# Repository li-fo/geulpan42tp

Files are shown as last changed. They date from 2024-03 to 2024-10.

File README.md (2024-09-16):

# GeulPan42TP Keyboard

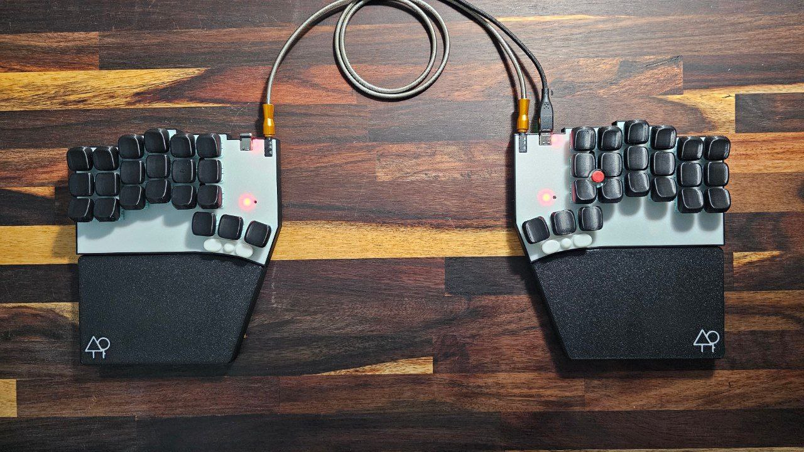
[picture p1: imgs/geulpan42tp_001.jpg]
GeulPan42TP


"GeulPan(글판)" means a keyboard.

GeulPan42TP is a split keyboard with 3x6 column staggered keys and 3 thumb keys.
and TrackPoint with 3 keys.

- MCU : YD-RP2040
- Trackpoint Module : 2-piece Tracpoint for X240, X250, X260 X270
    - if using tp mouse btn, can't drag. so need to use QMK Mouse btn
    - Ref [How to integrate a trackpoint in a mechanical keyboard](https://github.com/alonswartz/trackpoint)
- diodeless
- Split and rgblight (YD-RP2040 internal WS2812)
- tenting and palm rest
- keycap : [KLP LAME MX](https://github.com/braindefender/KLP-Lame-Keycaps)

### Ref Links

- [How to integrate a trackpoint in a mechanical keyboard](https://github.com/alonswartz/trackpoint)
- [TrackPoint](https://github.com/joric/jorne/wiki/Trackpoint)
- [TrackPoint Hardware from deskthority](https://deskthority.net/wiki/TrackPoint_Hardware)
- [TrackPoint System Version 4.0 Engineering Specification](https://blogs.epfl.ch/icenet/documents/Ykt3Eext.pdf)

## Caution

Although I made this and am currently using it, there appears to be a bug affecting the trackpoint operation. Therefore, unless using a trackpoint is essential for you, it may be better to consider a different split keyboard.

### Other Split keyboard with integrated trackpoint

- [TPS42](https://github.com/crehmann/TPS42)
- [Santoku Keyboard Kit](https://gestaltinput.com/products/santoku-keyboard-kit-black)

## Images

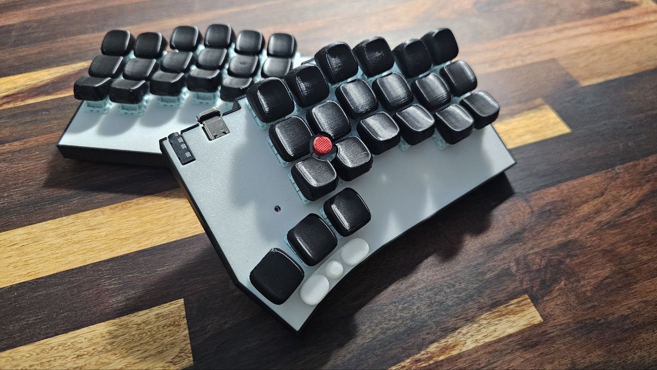
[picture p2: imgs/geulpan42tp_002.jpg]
GeulPan42TP


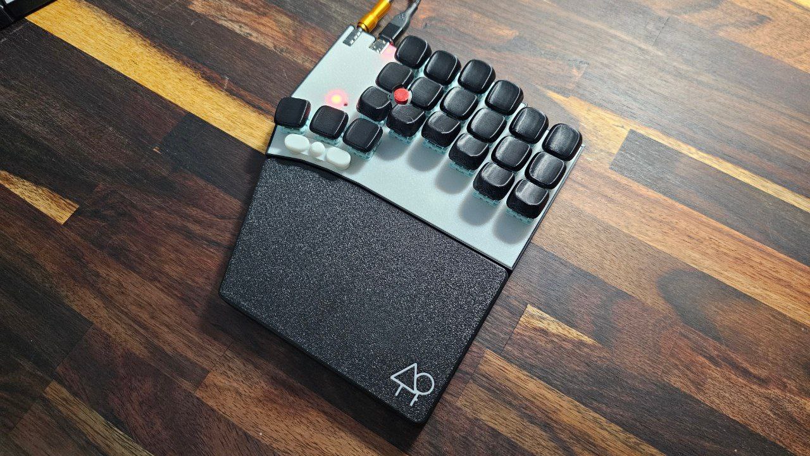
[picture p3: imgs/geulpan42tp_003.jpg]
GeulPan42TP


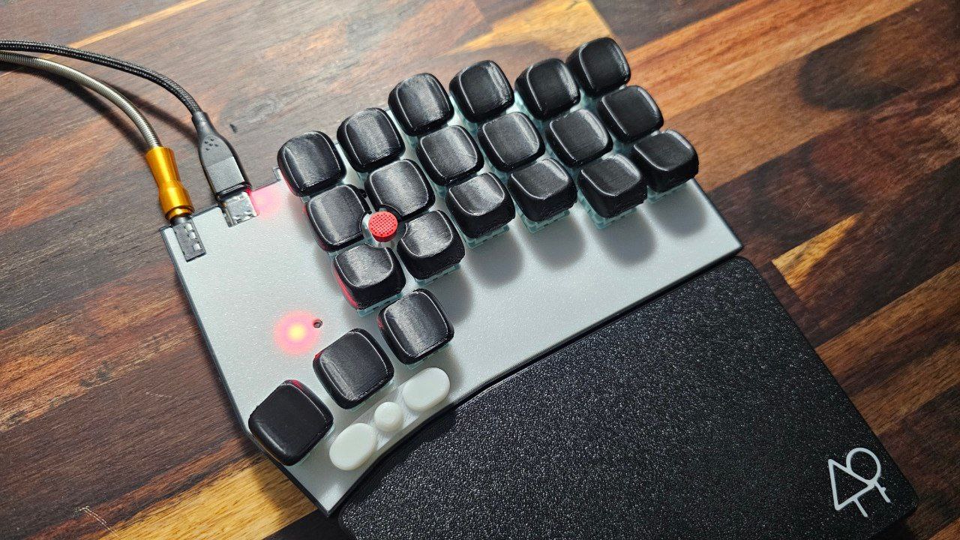
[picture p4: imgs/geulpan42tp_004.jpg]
GeulPan42TP


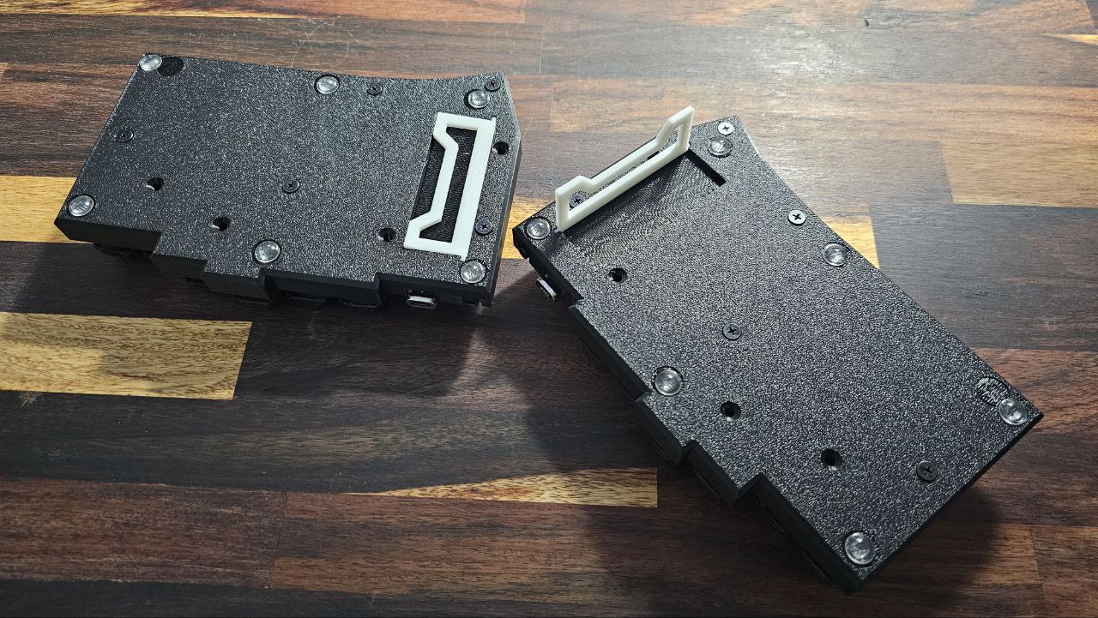
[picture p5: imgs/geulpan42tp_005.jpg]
GeulPan42TP


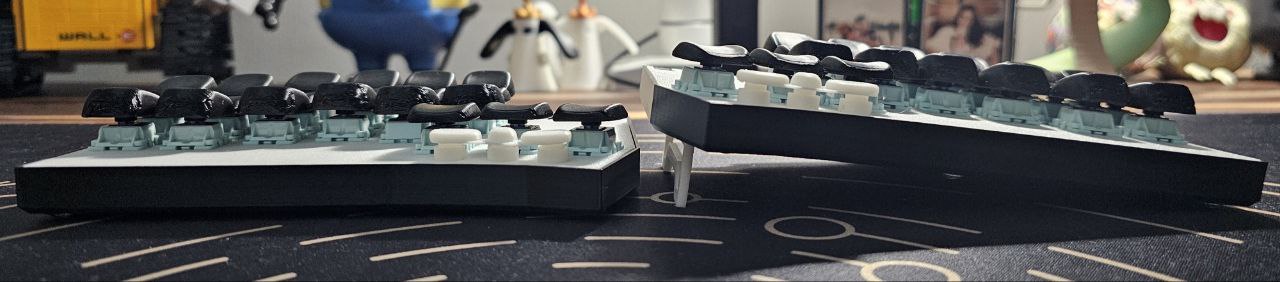
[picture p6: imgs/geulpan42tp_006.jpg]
GeulPan42TP


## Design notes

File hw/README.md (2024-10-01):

## BOM

### Base

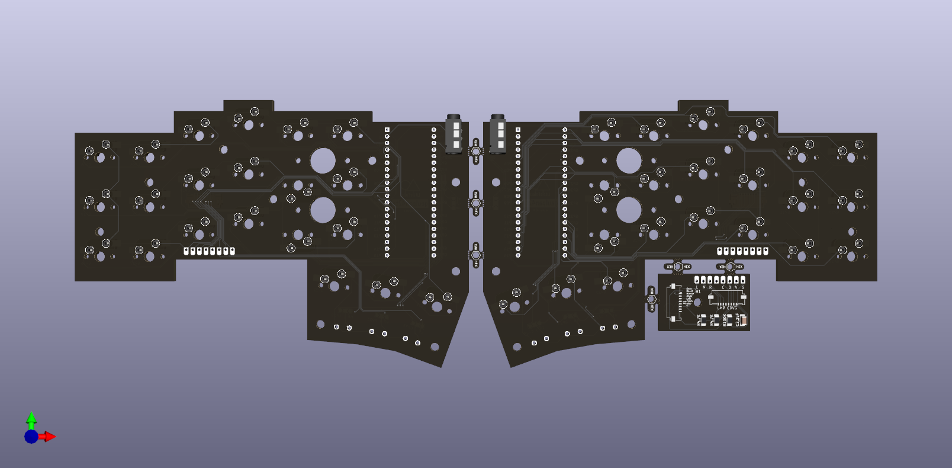
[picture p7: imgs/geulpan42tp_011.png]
GeulPan42TP


| Part  | Qty | Memo |
| --- | --- | --- |
| YD-RP2040  | 2  | -  |
| PJ321A  | 2 | -  |

### TrackPoint

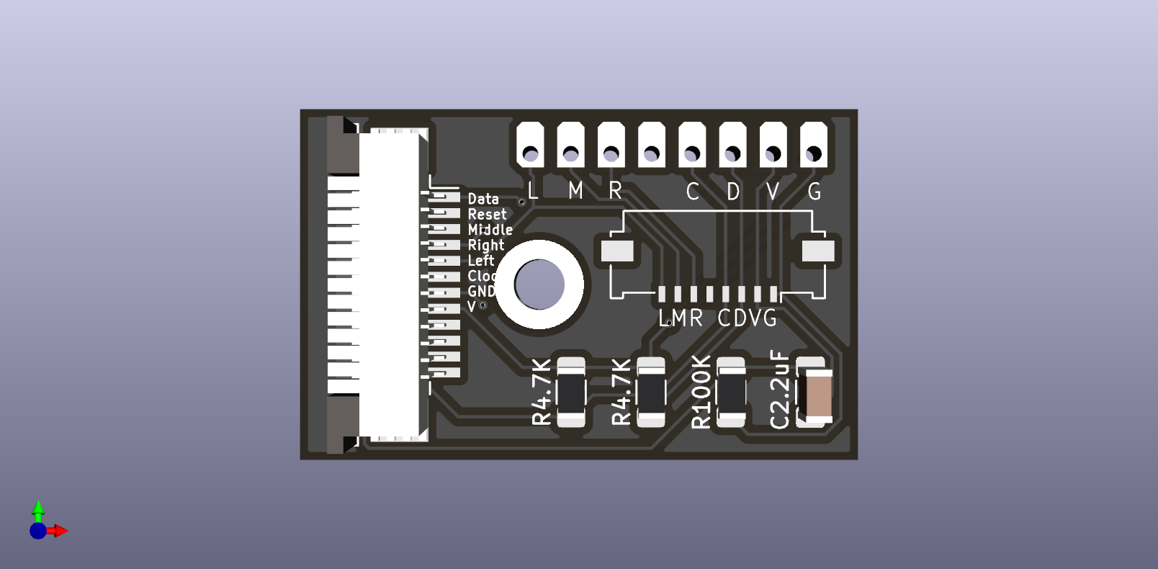
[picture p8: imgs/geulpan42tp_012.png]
GeulPan42TP


TrackPoint Module : 2-piece Tracpoint for X240, X250, X260 X270

| Part  | Qty | Size or Spec |
| --- | --- | --- |
| 4.7k  | 2  | 1206  |
| 100k  | 1 | 1206  |
| 2.2uF  | 1  | 1206  |
| FFC 12 Pin Connector*  | 1  | under contact  <br> if not a Molex 200528-0120, need to cut both ends of the cable |
| FFC 8 Pin Connector  | 2  | under contact |
| FFC 8 Pin Cable*  | 1  | reverse direction(right side, default) <br> forward direction (left side)  |
| 6x6x3.5  | 6  | -  |
| M2 x 4mm Philips flathead bolt | 2  | -  |

If you're not using an FFC cable, you can also solder it as shown in the picture.

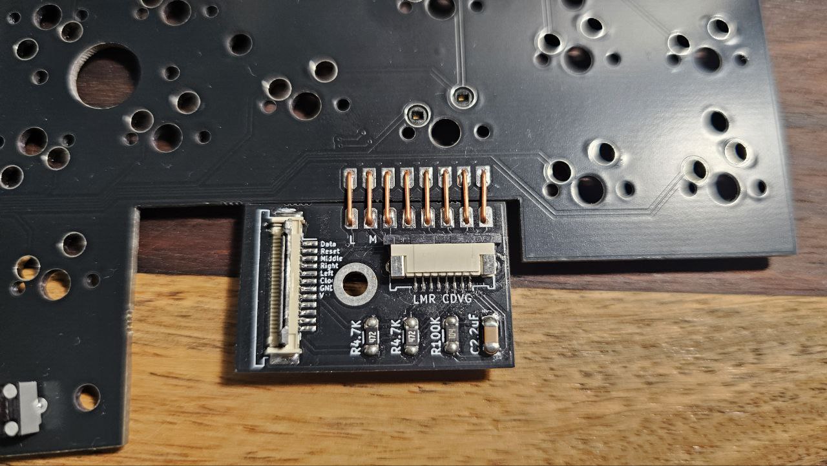
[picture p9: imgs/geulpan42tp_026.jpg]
GeulPan42TP


### Case & PalmRest

| Part  | Qty | Size |
| --- | --- | --- |
| Bolt  | 10  | M3 6mm  |
| Bumpon  | 12  | SJ5032 or 10mm  |
| Mganet | 6  | 6mm x 2mm  |

### Keycaps for Trackpoint

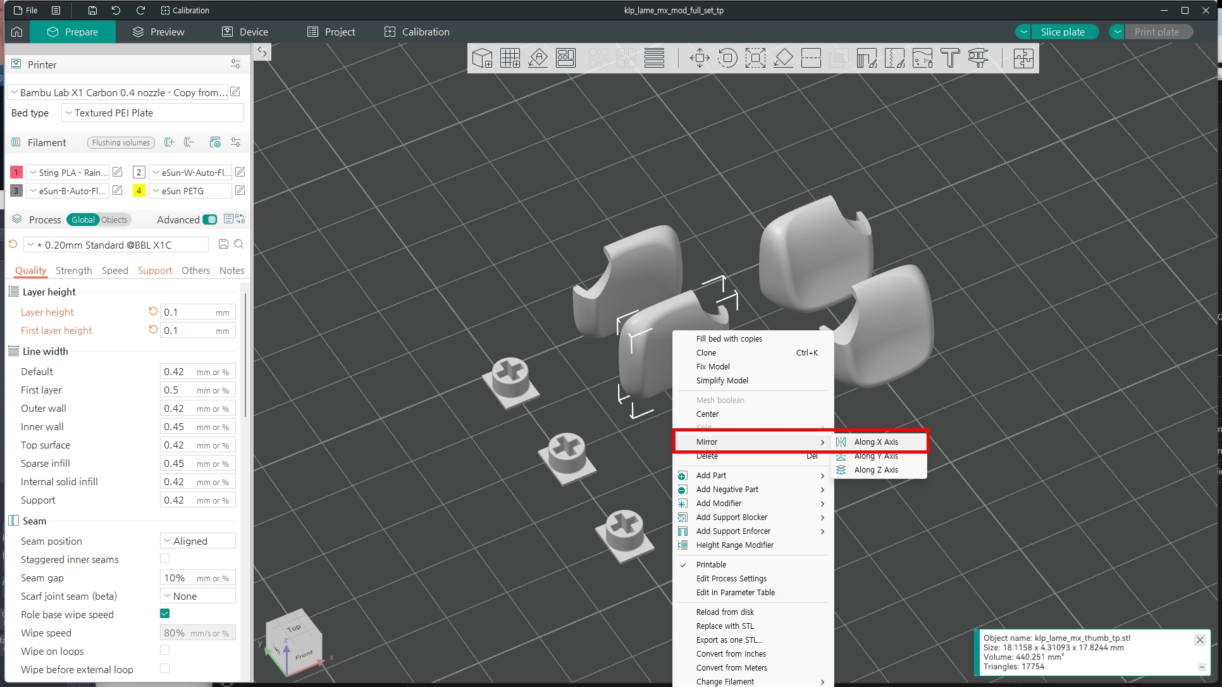
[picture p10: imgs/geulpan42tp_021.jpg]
GeulPan42TP


I have modified and created the [KLP Lame Sallde for MX](https://github.com/braindefender/KLP-Lame-Keycaps) keycap. The print settings are as follows:

| Option  | Value | Memo |
| --- | --- | --- |
| Layer Height  | 0.1 | - |
| Support  | Tree Support  | -  |

### Sodering Option

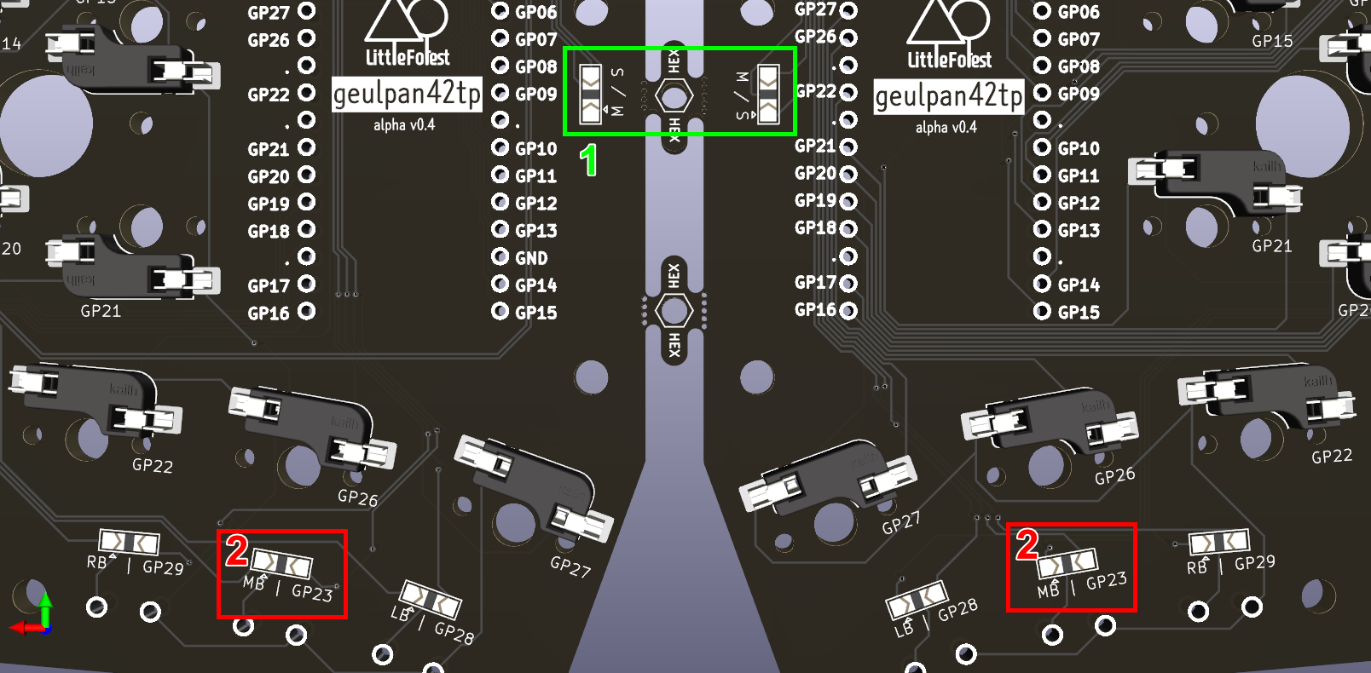
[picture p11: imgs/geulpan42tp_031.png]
GeulPan42TP


I'm primarily using the trackpoint attached on the right side by default, but I've made it possible to choose between master and slave for those who want to attach the trackpoint on the left side. However, I haven't tested it with the trackpoint mounted on the left side. 

1. Master or Slave
    -  I have set it up so that the side with the trackpoint installed is the master, and the side without it is the slave. Power is supplied from the master to the slave.
    - By default, the right side is the master and the left side is the slave
    - The default soldering position is marked as "▲"

2. Mouse Button 
    - The default soldering position is marked as "▲" and Using Trackpoint Mouse Button.
    - You can use either the trackpoint's mouse buttons or the QMK mouse buttons.If the trackpoint mouse operation is not smooth, you can switch to the QMK mouse buttons.
    - If using QMK mouse buttons, the left and right buttons can be used immediately by changing their soldering positions.
    - To use the middle mouse button as a QMK mouse button, you need to desolder the RGB section of the yd-rp2040 board.

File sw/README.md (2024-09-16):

# GeulPan42TP Keyboard

If you can't drag while using the trackpoint, please use "PS2_MOUSE_USE_REMOTE_MODE". 

However, for parts where the trackpoint is not connected, you should use "Stream Mode".

"PS/2 mouse" was not connected, using "remote mode" caused the controller to malfunction.

example : Master Side use "PS2_MOUSE_USE_REMOTE_MODE", Slave Side use "Stream Mode"

If the cursor malfunctions when using "remote mode", please reconnect the keyboard.

As a temporary solution to this problem, I have enabled the option to solder GP28 and GP29.
If you solder GP28 and GP29, you will be able to assign and use QMK mouse buttons.

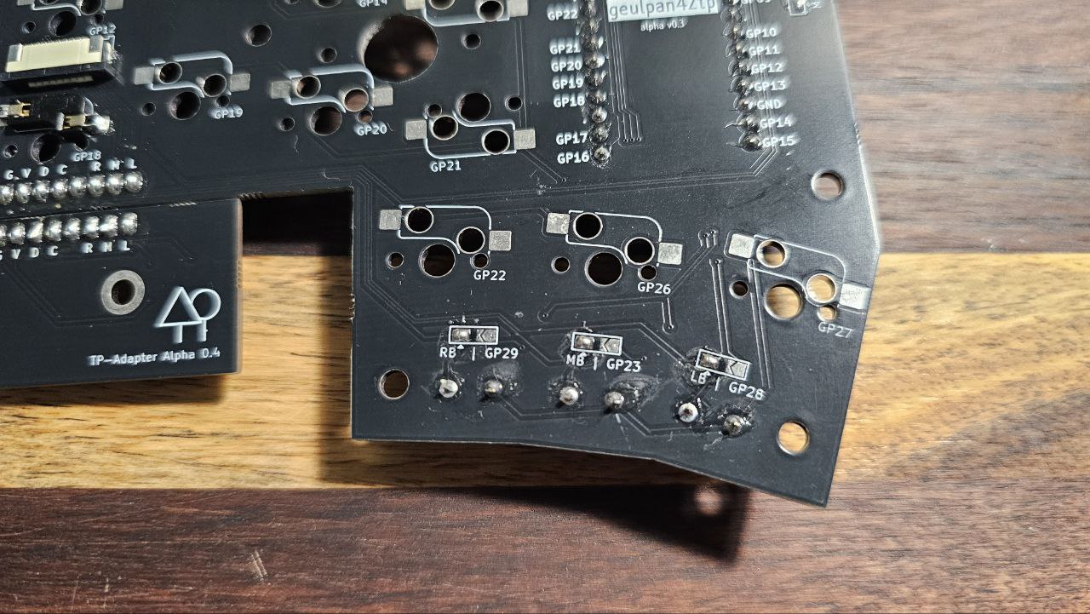
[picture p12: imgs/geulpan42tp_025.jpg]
GeulPan42TP


## TrackPoint movement activate mouse layer

When using the trackpoint, you can use the "Movement Hook" to automatically activate the mouse layer.
The default value is FALSE. This is because it was inconvenient when the trackpoint was often touched while typing.

To activate it, please change the "MOUSE_LAYER_AUTO_ENABLE" item in config.h from FALSE to TRUE.

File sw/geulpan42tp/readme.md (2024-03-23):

# GeulPan42TP Keyboard

"GeulPan(글판)" means a keyboard.

GeulPan42TP is a 42 keyboard with Trackpoint.

RP2040, split, diodeless, Trackpoint, rgblight(YD-RP2040 internal WS2812)

currently POC stage. 

- TrackPoint Module : 2-piece Trackpoint for X240, X250, X260 X270
    - if using tp mouse button, can't drag. so need to use QMK mouse button
    - Ref [How to integrate a trackpoint in a mechanical keyboard](https://github.com/alonswartz/trackpoint)

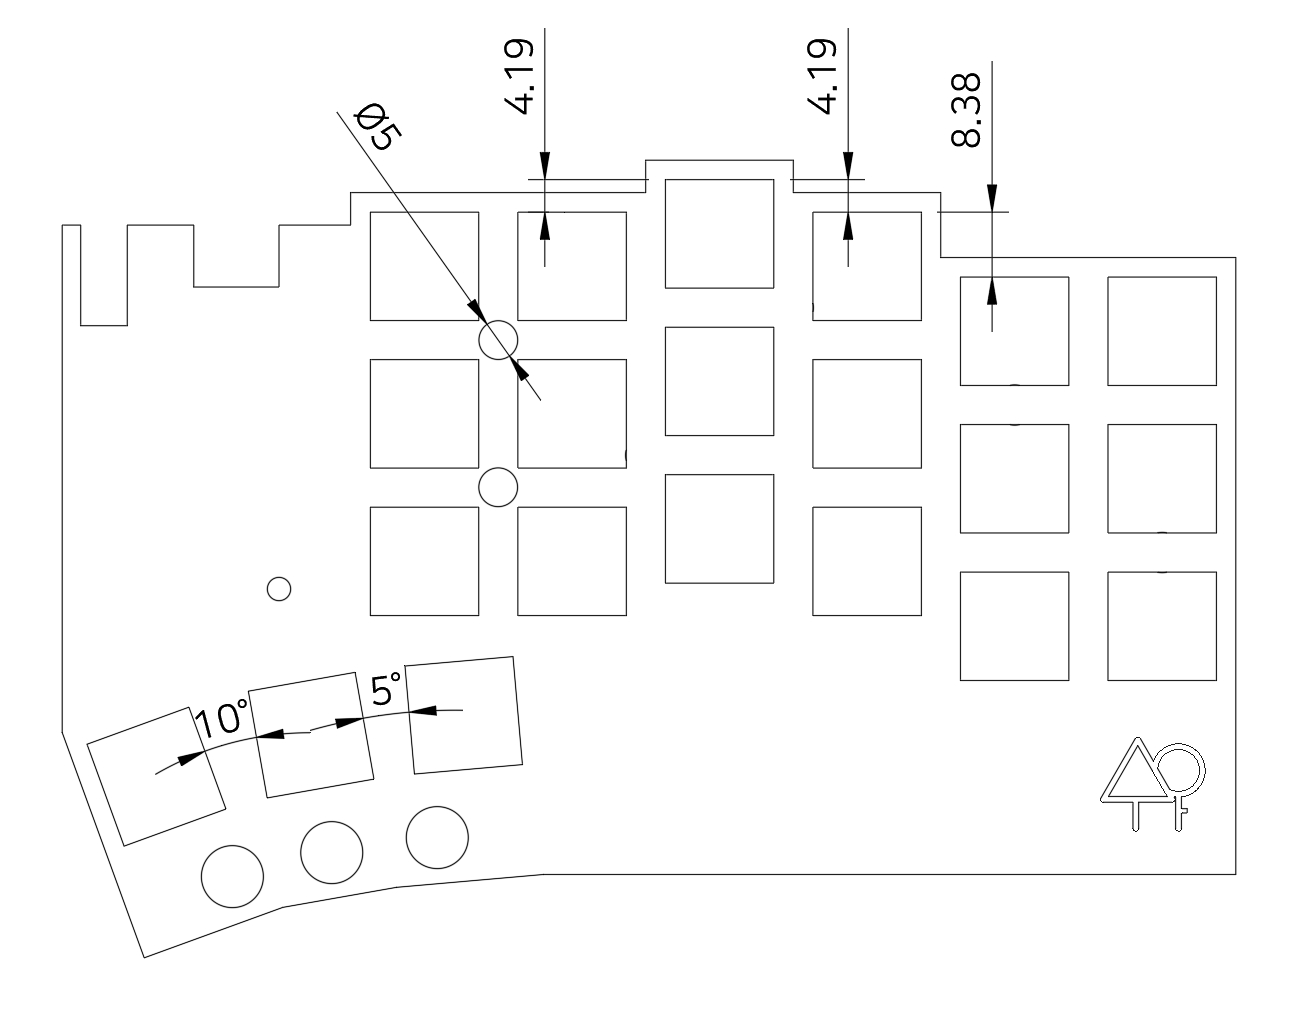
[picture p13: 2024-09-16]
imgs/geulpan42tp_007.jpg

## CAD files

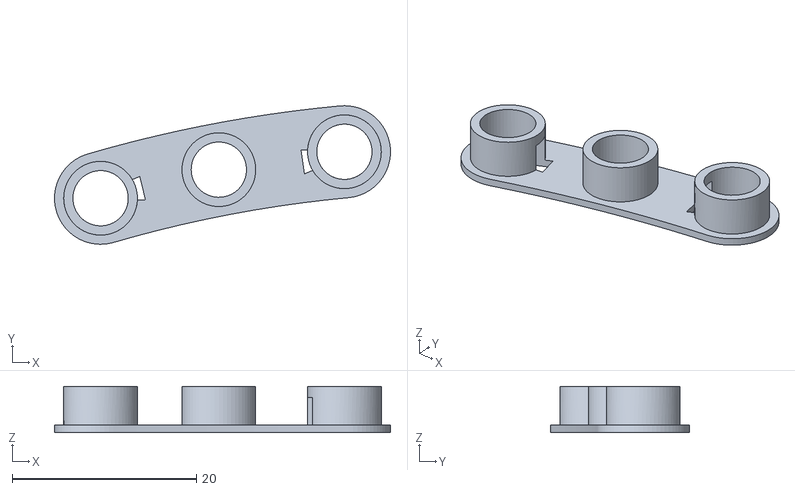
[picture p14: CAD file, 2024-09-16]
hw/stls/05-02 Mouse-BTN-Support.stl
36.5 x 15.0 x 5.00

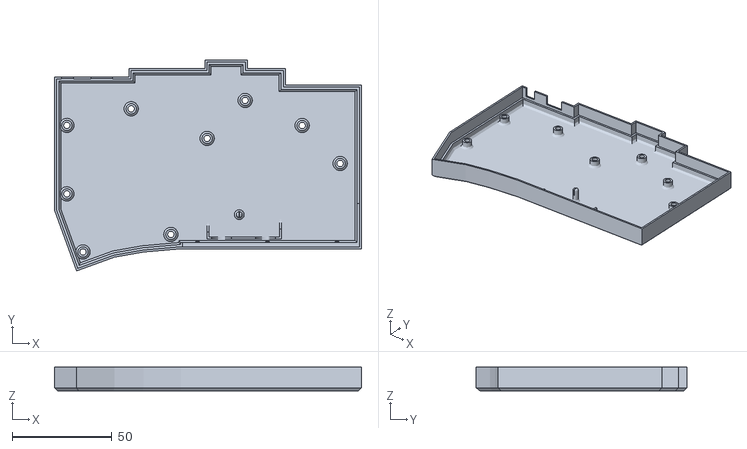
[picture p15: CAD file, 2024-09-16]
hw/stls/01 gp42tp-case-v0.1.stl
154.0 x 105.7 x 12.0

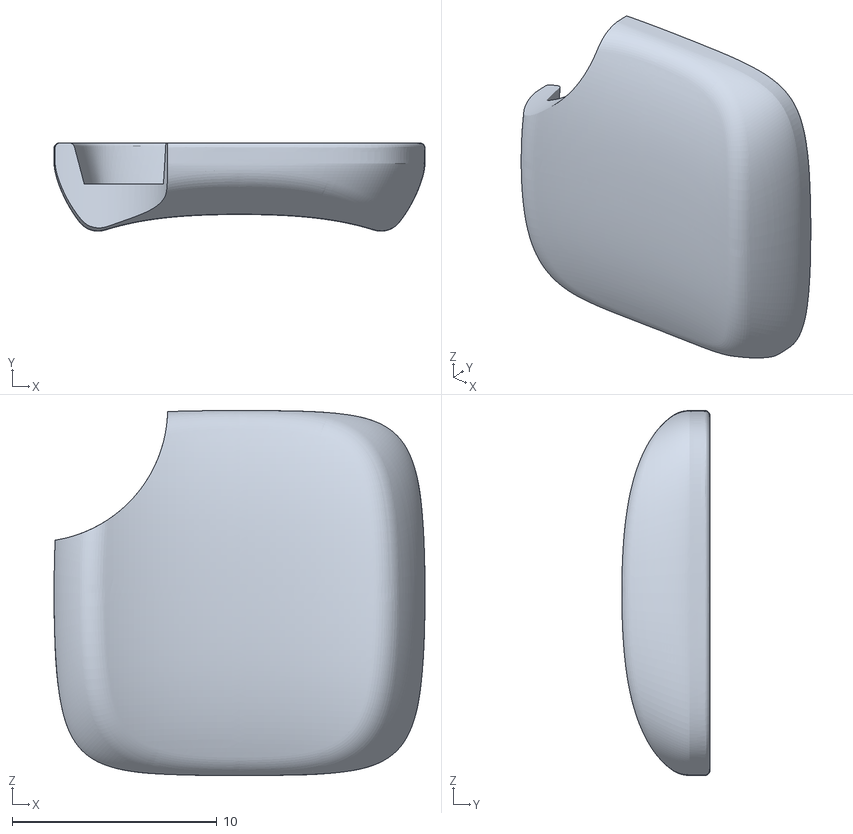
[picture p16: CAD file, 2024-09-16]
hw/stls/15 klp_lame_mx_thumb_tp.stl
18.1 x 4.31 x 17.8

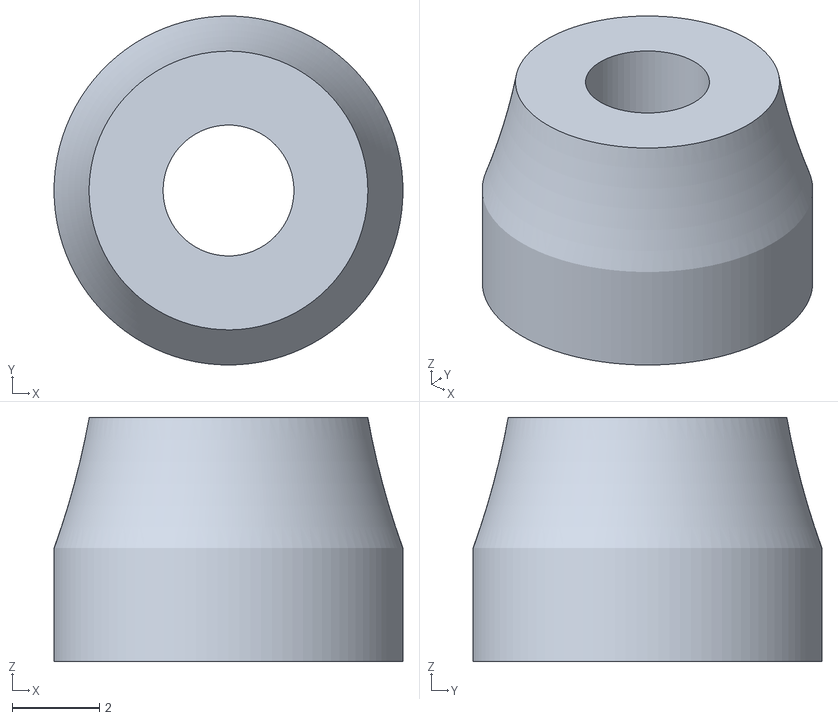
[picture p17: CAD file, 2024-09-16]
hw/stls/13 TrackPoint_pole_holder.stl
8.00 x 8.00 x 5.60

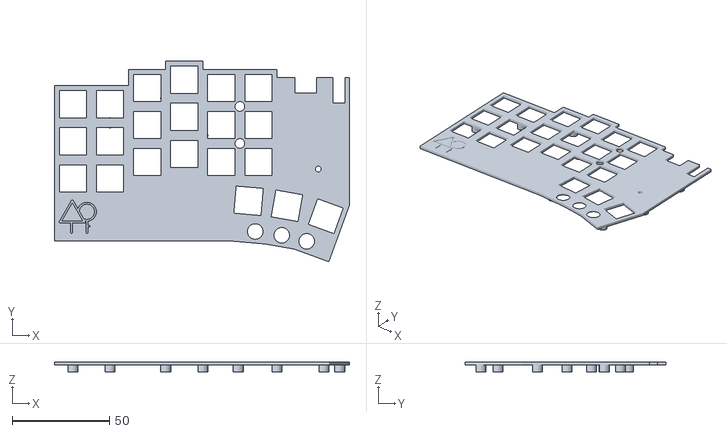
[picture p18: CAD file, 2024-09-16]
hw/stls/03-02 plate-left.stl
151.6 x 103.0 x 5.10

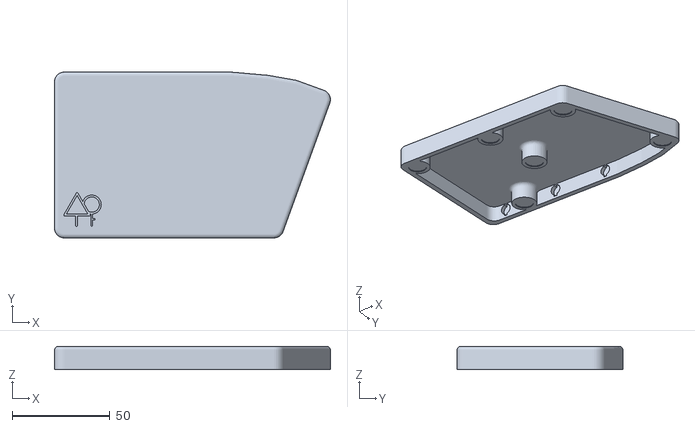
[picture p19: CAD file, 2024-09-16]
hw/stls/10 palmrest-noCusion-left.stl
141.5 x 85.0 x 12.0

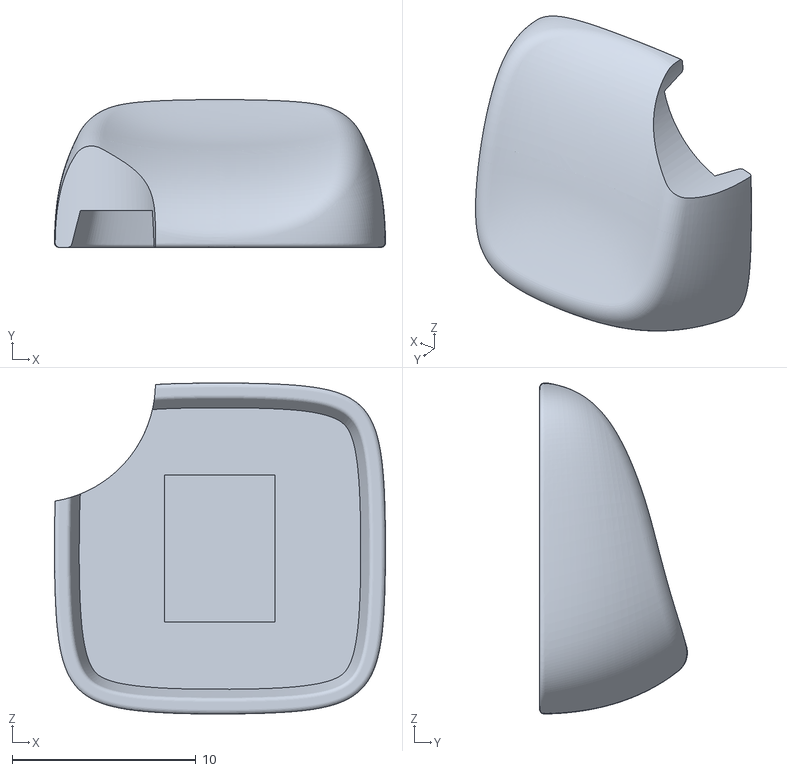
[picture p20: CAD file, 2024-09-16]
hw/stls/15 klp_lame_mx_tilted_tp.stl
18.0 x 8.04 x 18.0

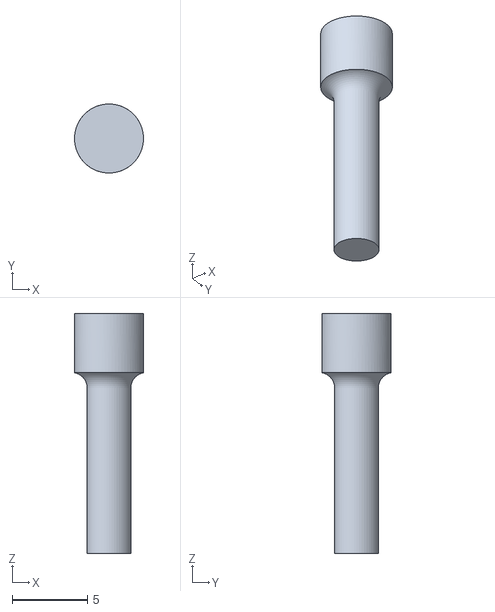
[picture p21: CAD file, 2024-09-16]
hw/stls/13 TrackPoint_pole_16mm.stl
4.60 x 4.60 x 16.0

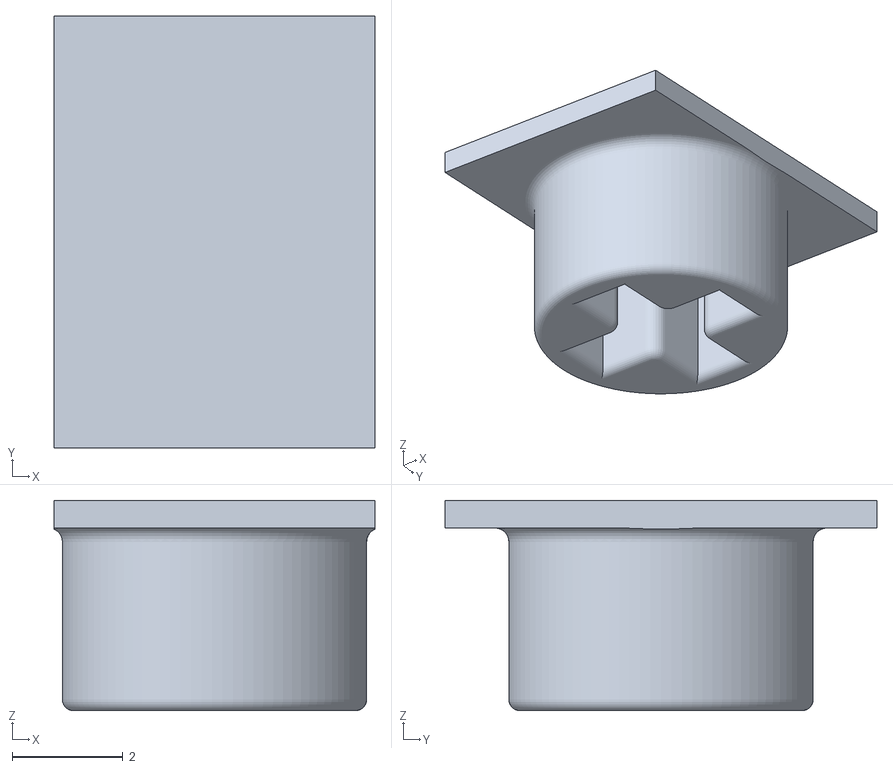
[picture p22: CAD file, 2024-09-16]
hw/stls/15 mx_pole.stl
5.80 x 7.80 x 3.80

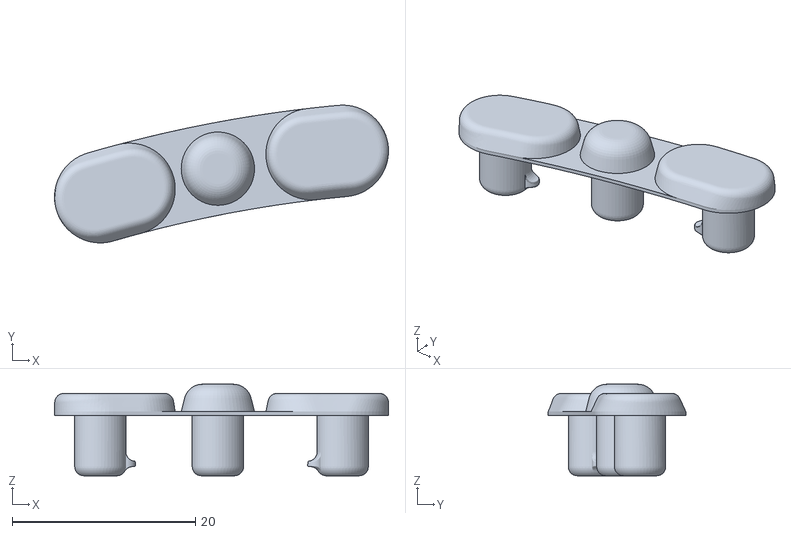
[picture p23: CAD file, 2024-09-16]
hw/stls/05-01 Mouse-BTN.stl
36.5 x 15.0 x 10.0

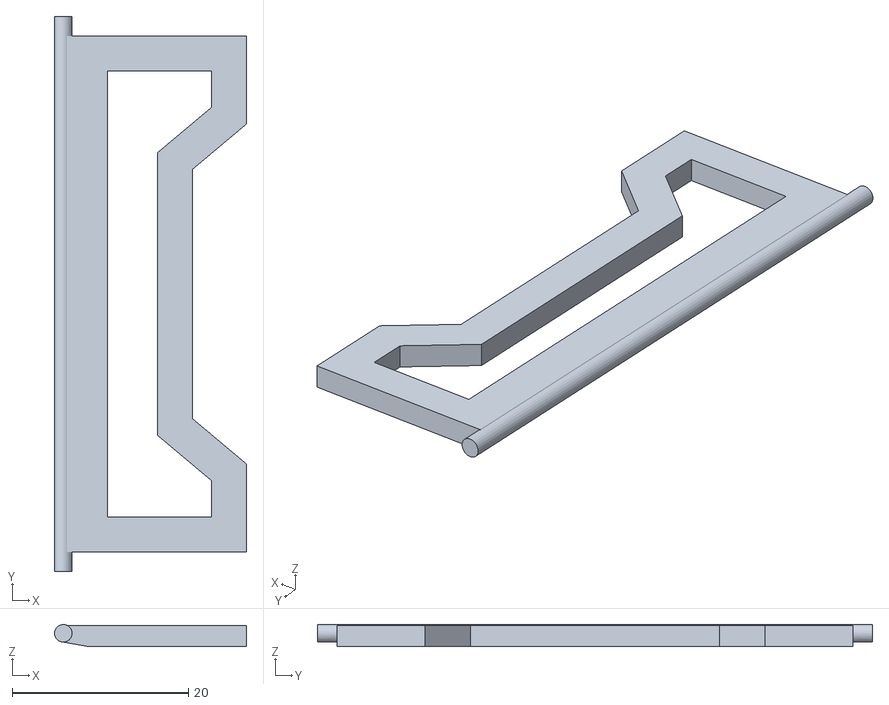
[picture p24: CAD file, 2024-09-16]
hw/stls/02 gp42tp-case-v0.2-stand-pin-long.stl
21.8 x 63.0 x 2.50

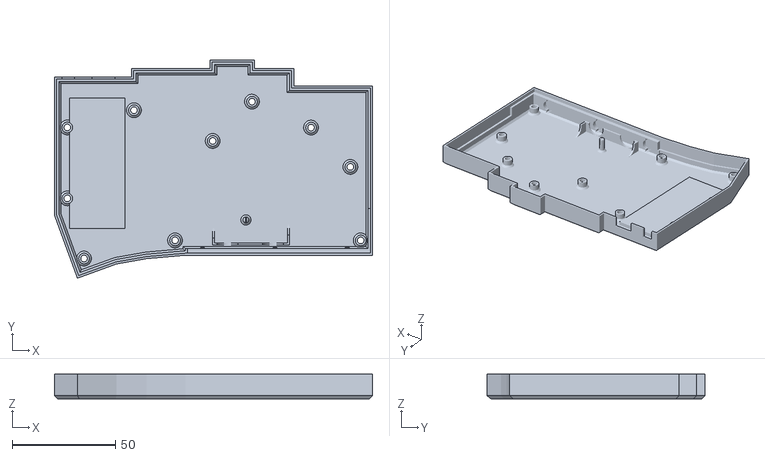
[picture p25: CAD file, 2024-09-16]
hw/stls/02 gp42tp-case-v0.2-stand-long.stl
154.0 x 105.7 x 12.0

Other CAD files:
hw/stls/10 palmrest-noCusion-right.stl
hw/stls/03-02 plate-right.stl

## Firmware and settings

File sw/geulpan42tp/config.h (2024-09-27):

#pragma once
// split config
#define SERIAL_PIO_USE_PIO0
#define SERIAL_USART_FULL_DUPLEX   // Enable full duplex operation mode.
#define SERIAL_USART_TX_PIN GP0    // USART TX pin
#define SERIAL_USART_RX_PIN GP1    // USART RX pin

// trackpoint
#define PS2_PIO_USE_PIO1
#define PS2_CLOCK_PIN   GP3
#define PS2_DATA_PIN    GP2

// scrolling control. default value 2
// #define PS2_MOUSE_SCROLL_DIVISOR_H 24
// #define PS2_MOUSE_SCROLL_DIVISOR_V 24

// if trackpoint btn can't using Drag, using "PS2_MOUSE_USE_REMOTE_MODE"
// If the mouse cursor malfunctions, you can comment out "PS2_MOUSE_USE_REMOTE_MODE" and use QMK's mouse buttons.
// #define PS2_MOUSE_USE_REMOTE_MODE 

// mouse movement activate mouse layer
// 
#define MOUSE_LAYER_AUTO_ENABLE FALSE

// WS2812
// If WS2812 does not work, check soldering on the RGB(or R68) pad 
#define WS2812_PIO_USE_PIO2 // Force the usage of PIO1 peripheral, by default the WS2812 implementation uses the PIO0 peripheral
#define WS2812_DI_PIN GP23  // The pin connected to the data pin of the LEDs
#define RGBLIGHT_LED_COUNT 1 // The number of LEDs connected  
#define RGBLED_NUM 1 

// RGBLIGHT
#define RGBLIGHT_SPLIT 
#define RGBLIGHT_EFFECT_BREATHING
#define RGBLIGHT_EFFECT_RAINBOW_MOOD
#define RGBLIGHT_EFFECT_RAINBOW_SWIRL
#define RGBLIGHT_EFFECT_SNAKE
#define RGBLIGHT_EFFECT_KNIGHT
#define RGBLIGHT_EFFECT_CHRISTMAS
#define RGBLIGHT_EFFECT_STATIC_GRADIENT
#define RGBLIGHT_EFFECT_RGB_TEST
#define RGBLIGHT_EFFECT_ALTERNATING
#define RGBLIGHT_EFFECT_TWINKLE
                                                                                                                                    
// press reset btn twice, to enter bootleader( if use this option,"bootsetl + reset" btn will not workig )                        
#define RP2040_BOOTLOADER_DOUBLE_TAP_RESET
#define RP2040_BOOTLOADER_DOUBLE_TAP_RESET_TIMEOUT 1000U
                                                          
/* key matrix size */
#define MATRIX_ROWS 8
#define MATRIX_COLS 6

#define MASTER_RIGHT //tp module installed on right side

// Left - PCB 기준
#define DIRECT_PINS { \
    {GP4, GP5, GP6, GP7, GP8, GP9}, \
    {GP10, GP11, GP12, GP13, GP14, GP15}, \
    {GP16, GP17, GP18, GP19, GP20, GP21}, \
    {GP22, GP26, GP27, GP29, NO_PIN, GP28}, \
}

// Right - PCB & hanwired
#define DIRECT_PINS_RIGHT { \
    {GP9, GP8, GP7, GP6, GP5, GP4}, \
    {GP15, GP14, GP13, GP12, GP11, GP10}, \
    {GP21, GP20, GP19, GP18, GP17, GP16}, \
    {GP27, GP26, GP22, GP28, NO_PIN, GP29}, \
}

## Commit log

2024-09-15 mod about led count and trackpoint btn
2024-09-15 mod led config and rebuild firmware for PCB Version
2024-09-16 PCB Version
    [01 01 geulpan_42tp left v02 mcu 1.3mm.stl, 01 01 geulpan_42tp right v02 mcu 1.3mm.stl, 01 02 geulpan_42tp left v02 mcu 1.7mm.stl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]
2024-09-18 add solder jumper info
2024-09-19 add ffc cable direction info
2024-10-01 bolt size mod
